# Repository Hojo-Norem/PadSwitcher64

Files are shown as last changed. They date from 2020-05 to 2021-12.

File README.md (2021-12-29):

# PadSwitcher64
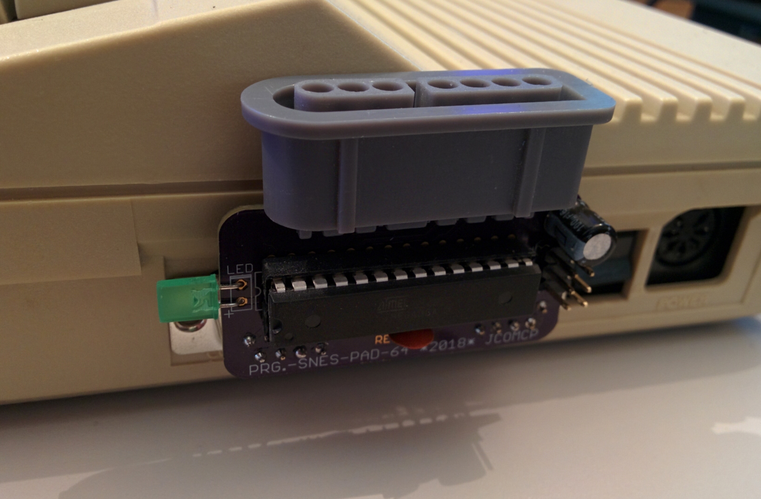
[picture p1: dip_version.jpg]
PadSwitcher64: DIP version

Interface to allow Super Nintendo (SNES) control pads to be plugged into a C64's joystick ports.

The adapter connects to both C64 joystick ports and allows the active port to be changed on the fly with a push of a button.  The interface defaults to joystick port two on power on.

Also, the interface allows up to four custom mappings to be programmed using a C64-side application.  The custom mappings allow any combination of joystick port two and port one control lines to be mapped to any of the Super Nintendo controller action buttons (A,B,X,Y,L,R).  Any of the action buttons can also have an optional rapid-fire function applied, of which a normal and 'inverted' state is available.  'Inverted' rapid fire is simply that when active the output state of the effected button will be opposite to of a normal rapid fire button when pushed.  For example, mapping a button to joystick left with rapid fire and another button to joystick right with inverted rapid fire will simulate a rapid left/right joystick waggle when both buttons are pushed.

This code was originally developed for the Atmel ATMega8 mcu and was then later ported over to the ATMega88.  This was mainly due to the availability of the Mega8 and that the Mega88 has more power saving features.

This source code was written using AVR-GCC and AVR Libc.  The C64-side software was written in Notepad++, tokenised to CBM BASIC using C64List and then compiled using "BASIC 64".  The machine code portion was assembled using 64tass.

**A pre-compiled HEX file for the AVR and the C64-side software for setting the custom mappings can be found in the releases section.  Once sucessfully programmed, the LED indicator will flash for a couple of seconds on every subsiquent power-on.**

**Mega88 fuse settings: CKDIV8 disabled, all other fuses at factory defaults.**

**PCB has been uploaded to OSH Park ( https://oshpark.com/shared_projects/Fk2LAkUS ) where they can be ordered in multiples of three.**
	
# TODO :
  * Re-jig command mode for potential compatibility with non-C64 Atari joystick compatible machines.
  * Maybe figure out how to support two pads while still retaining some semblance of mapping support.
	
# Pad Mapping: (default)
|SNES|C64|
|---|---|
|DPAD UP|UP|
|DPAD DOWN|DOWN|
|DPAD LEFT|LEFT|
|DPAD RIGHT|RIGHT|
|Y|FIRE|
|X|TURBO FIRE|
|B|UP|
|A|'Special'(*1)|
|R|KEYBOARD MATRIX LINE(PORT 2 MODE ONLY)(*2)|

(*1) -  UP + FIRE or DOWN + FIRE, swapped with SELECT + L.

(*2) - Defaults to PB4 which most software will interpret as the SPACEBAR.

# Fixed Controls:
|Button/Combo|Function|
|---|---|
|SELECT + UP|Toggle disable of D-PAD UP|
|START|Swap Joystick control port|
|SELECT + L|Toggle 'Special' function|
|SELECT + R|Change keyboard matrix line (*3)|
|SELECT + DOWN|Toggle TURBO FIRE rate|
|SELECT + (A,B,X,Y)|Select mapping| 
|SELECT + START|Default Mapping|	
|SELECT + START|Enter Command Mode (*4)| 
|SELECT + START + L + R| |
|(In normal or mapped mode)|Enter type 1 direct mode|
|(In any other mode)|Force normal mode|

(*3) - Joystick port 1, which corresponds to CIA 1 PB0 to PB4, PB4 which are normally used as the keyboard input lines during keyboard scanning.  By default at startup this is set to PB4, which most software will interpret as the SPACEBAR.
|CIA1 PortB|CIA1 PA7|PA6|PA5|PA4|PA3|PA2|PA1|PA0|
|---|---|---|---|---|---|---|---|---|
|**PB4**|SPACE|R-SHIFT|.|M|B|C|Z|F1/F2|
|**PB3**|2|CLR/HOME|-|0|8|6|4|F7/F8|
|**PB2**|CTRL|;|L|J|G|D|A|CRSR|->/<-|
|**PB1**|<-|*|P|I|Y|R|W|RETURN|
|**PB0**|1|£|+|9|7|5|3|INST/DEL|

(*4) - Only functional when prompted, only functional in default mapping mode.

# MAPPING
Four mappings, each with all 6 action buttons available.  Each button has a 2 byte pattern corresponding to the following:
|Byte/Bit|Function|
|---|---|
|Byte 1 - Bit 0 to 3|PB0 to PB3 (JOY 1 Directions & KB matrix)|
|Byte 1 - Bit 4 to 7|PA0 to PA3 (Joy 2 directions)|
|Byte 2 - Bit 0|PB4 (Joy 1 Fire & KB matrix)|
|Byte 2 - bit 1|PA4 (Joy 2 Fire)|
|Byte 2 - bit 2|Pad Button has turbofire action|
|Byte 2 - Bit 3|Pad Button has turbofire action (inverted)|
		
Bits 4 - 7 of byte 2 are not accessible through the command interface at this time.
			
# Direct mode - Type 1
Direct mode allows all the SNES control pad buttons to be read by the C64.  Type 1 uses both joystick port to report all buttons.  There is technically a direct mode type 2, and that is by using the command interface.  Type one is much faster as it just involves reading the joystick ports normally. 
|SNES Pad|C64 CIA|Bit pattern|C64 Joystick|
|---|---|---|---|
|Up|DC00| 11110|Port 2 up|
|Down|DC00|11101|Port 2 down|
|Left|DC00|11011|Port 2 left|
|Right|DC00|10111|Port 2 right|
|Y|DC00|01111|Port 2 fire|
|Start|DC00|00000|Port 2 all|
|B|DC01|11110|Port 1 up|
|X|DC01|11101|Port 1 down|
|L|DC01|11011|Port 1 left|
|R|DC01|10111|Port 1 right|
|A|DC01|01111|Port 1 fire|
|Select|DC01|00000|Port 1 all|

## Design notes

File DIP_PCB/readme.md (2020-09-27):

# BOM

1 x Atmel/Microchip AVR ATMega88 in 28 pin DIP package.  Any speed grade will do.

(Optional) 1 x 28 pin DIP socket.  If you ommit this part the the resistor will need to be soldered
  to the reverse side of the PCB, taking care to leave as little amount of leg protruding underneath
  as possible.

1 x 330 Ohm resistor

1 x LED (any regualr LED will do)

1 x 100nF ceramic capacitor

1 x 100uF electrolytic capacitor

1 x 3-by-2 pin header.  Optional if you are going to program the AVR out of circuit.

1 x SNES control port socket.  Straight pin or right angled by your preference.  The PCB is able to accomodate
  the sockets that use the thicker pins.

2 x Female DB9 plug/socket with straight PCB mounts.  When soldering I recommend spacing them out from the PCB
  a couple of mm.

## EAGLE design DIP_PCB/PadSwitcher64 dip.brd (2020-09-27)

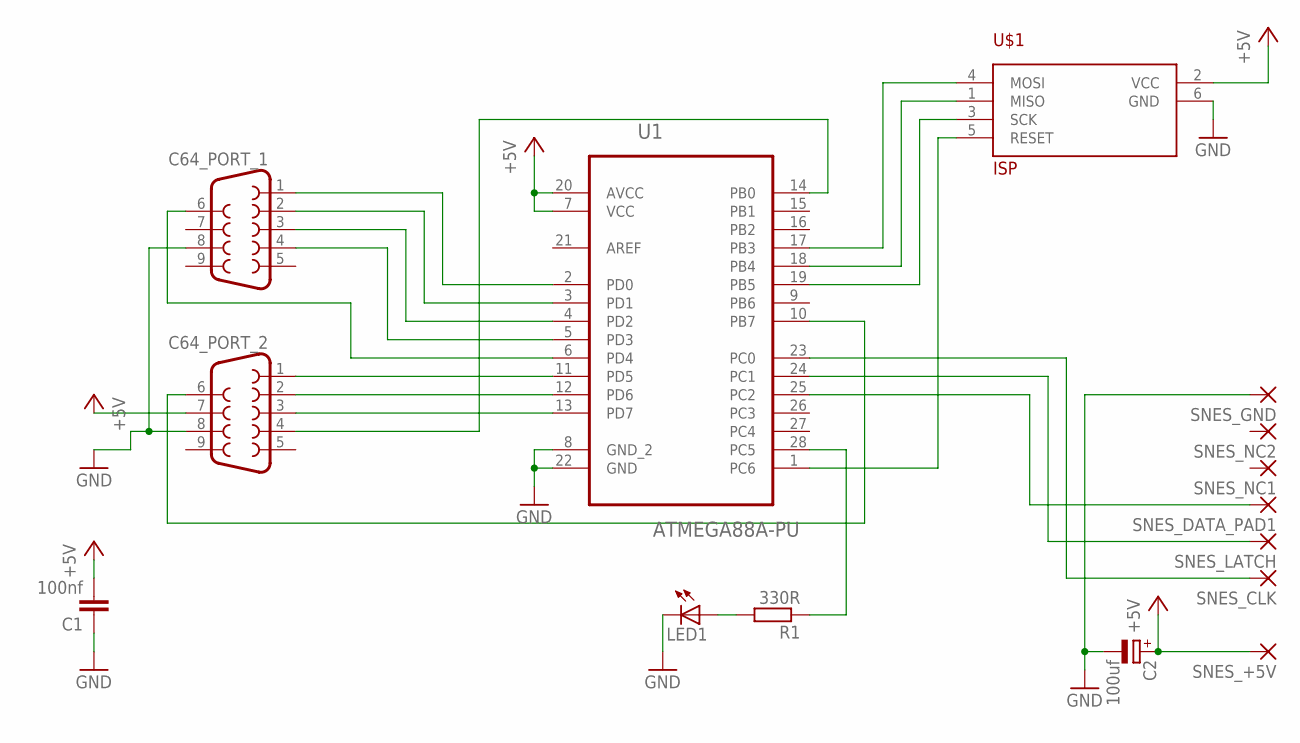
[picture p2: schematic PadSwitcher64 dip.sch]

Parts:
C1: 100nf; C050-024X044
C2: 100uf; E2,5-5
C64_PORT_1, C64_PORT_2: F09; F09VB_NO_SHELL
LED1: LEDSQR2X5; LED2X5
R1: 330R; 0207/10
SNES_+5V: 3,17/1,1
SNES_CLK: 3,17/1,1
SNES_DATA_PAD1: 3,17/1,1
SNES_GND: 3,17/1,1
SNES_LATCH: 3,17/1,1
SNES_NC1, SNES_NC2: 3,17/1,1
U1: ATMEGA88A-PU; DIL28-3
U$1: ISP; MA03-2

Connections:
+5V: C1.2, C2.+, C64_PORT_2.7, SNES_+5V.1, U1.7 (VCC), U1.20 (AVCC), U$1.2 (VCC)
GND: C1.1, C2.-, C64_PORT_1.8, C64_PORT_2.8, LED1.K (C), SNES_GND.1, U1.8 (GND_2), U1.22 (GND), U$1.6 (GND)
unnamed: U1.1 (PC6), U$1.5 (RESET)
unnamed: U1.19 (PB5), U$1.3 (SCK)
unnamed: U1.18 (PB4), U$1.1 (MISO)
unnamed: U1.17 (PB3), U$1.4 (MOSI)
unnamed: C64_PORT_1.1, U1.2 (PD0)
unnamed: C64_PORT_1.2, U1.3 (PD1)
unnamed: C64_PORT_1.3, U1.4 (PD2)
unnamed: C64_PORT_1.4, U1.5 (PD3)
unnamed: C64_PORT_1.6, U1.6 (PD4)
unnamed: C64_PORT_2.6, U1.10 (PB7)
unnamed: C64_PORT_2.1, U1.11 (PD5)
unnamed: C64_PORT_2.2, U1.12 (PD6)
unnamed: C64_PORT_2.3, U1.13 (PD7)
unnamed: C64_PORT_2.4, U1.14 (PB0)
unnamed: SNES_CLK.1, U1.23 (PC0)
unnamed: SNES_LATCH.1, U1.24 (PC1)
unnamed: SNES_DATA_PAD1.1, U1.25 (PC2)
unnamed: R1.1, U1.28 (PC5)
unnamed: LED1.A, R1.2

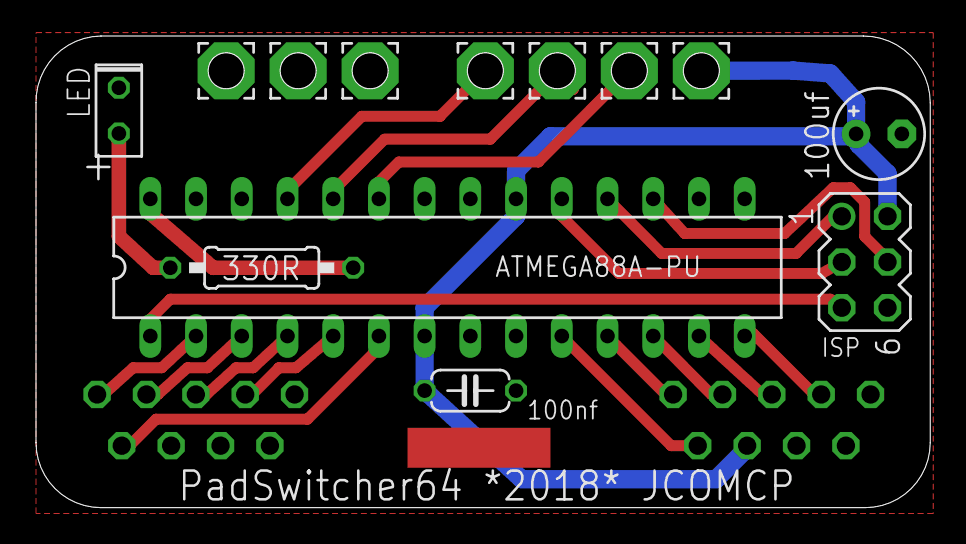
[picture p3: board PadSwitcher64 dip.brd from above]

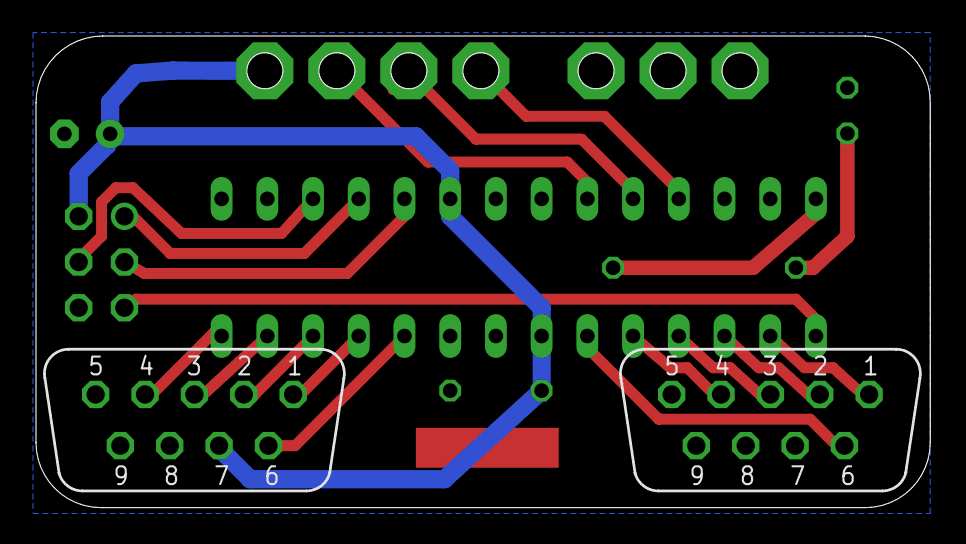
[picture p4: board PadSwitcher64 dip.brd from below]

Board: 2 copper layers, 49.7 x 26.2 mm, 15 parts (2 on the bottom side), 21 nets.

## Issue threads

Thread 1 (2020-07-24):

PadSwitcher64 C64 software doesn't appear to work on NTSC machines

misterblack1, 2020-07-24:
Running the PRG, it asks to hit start and select on the control pad. When I do this, there is a slight flash on the screen and then a few seconds later it says "Communication Timeout with the interface!"

PadSiwtcher64 does work fine otherwise -- and pressing the button on joystick 2 enters a regular test screen and all the functions are working properly.

Is there anything I can do to troubleshoot?

Adrian (from Adrian's Digital Basement)

Hojo-Norem, 2020-07-24:
Hi.  The screen flash is a little debugging indicator.  The fact that it just
flashes and does not stick tells me that it is working to a degree.  It just
looks like that the effect that the difference in CPU clock speed between PAL
and NTSC is greater than I thought and the negotiation just times out sooner
on NTSC.

I've tripled the timeout length and attached the updated executable.  If it
works for you I'll update the GitHub.

[PadSwitcher64.zip](https://github.com/Hojo-Norem/PadSwitcher64/files/4970655/PadSwitcher64.zip)

misterblack1, 2020-07-30:
Ok sorry for the delay in testing. Just gave it a try and sadly no luck!

https://www.youtube.com/watch?v=v7ZLdolSgAk&feature=youtu.be

Different but still a timeout. Incidentally I tested this machine using Sven's diagnostic test harness and it shows up as fully working (in case there might be a 6526 issue)

Hojo-Norem, 2020-07-30:
Okay.  There should be no trouble with your hardware, it's just my underestimation of the differences between PAL and NTSC.  If there was HW issue then there's a good chance that the interfere would refuse to even begin handshaking and you would see no reaction at all on screen.

With the first version, did the border remain black or coloured after the flash?  A brief flash to black means there's a timeout during 'normal' communication while a solid white or red border means timeout during handshaking.

Try this build.  I had forgotten that there are three separate timeout checks in my code and I had gone and altered the wrong one!

[PadSwitcher64.zip](https://github.com/Hojo-Norem/PadSwitcher64/files/4999527/PadSwitcher64.zip)

misterblack1, 2020-07-30:
It was red -- check out the youtube video I posted there you can see it in action. :-)

Ok I'll try the next build and see.

Hojo-Norem, 2020-07-30:
Thanks.  If it still does not work, keep an eye on the LED on the interface.  Depending on where the timeout is occurring, the LED will flash for roughly two seconds or roughly five seconds.

misterblack1, 2020-08-01:
https://youtu.be/e2LAi0TGnCE

Hi unfortunately it's still not working. I used your updated 30th of July version and no visible change. See video. I also recorded what the LED is doing -- it's the two second flash.

Hojo-Norem, 2020-08-01:
I think I'm getting down to the source of the problem, but at the moment I'm not much closer on a solution.

Compare what you see with what supposed to happen: https://youtu.be/BsXZNpseAn4

What is a flicker of a few dozen raster lines on my PAL machine is tens of frames on your NTSC model.  The short blink sequence on the interface tells me that the handshake is timing out on the interface side first.  I wonder if the 60Hz refresh and associated interrupts are fouling things up...

I'm going to re-write the communications section in assembly.  At least that way I can disable interrupts during communications and I can't be sure of how the compiled BASIC is behaving in NTSC land.

Hojo-Norem, 2020-08-02:
Okay, re-write done.  It seems that the main issue stemmed from the C64 acting too quickly because even my poor attempt at 6502 machine code is faster than the compiled BASIC.  Fast enough that it broke until I put delays into the code.

Give this one a try.  If it does not work and the time-out border is CYAN, hit RUN/STOP+RESTORE as prompted then enter:
`POKE 50000,20`
`POKE 50001,64`
`POKE 50002,128`
`POKE 50003,5`
before typing RUN.  If it STILL does not work, re-type the last POKE, increase the 5 to 6 and re-RUN.

[PadSwitcher64.zip](https://github.com/Hojo-Norem/PadSwitcher64/files/5012663/PadSwitcher64.zip)

Hojo-Norem, 2020-09-09:
Hi.  Any chance to try this version yet?

misterblack1, 2020-09-22:
Hi!! Sorry I have just been so busy. Let me test it out right now. I'm intending to put out the video with your PadSwitcher64 this weekend, so it would be great to get this working for NTSC machines. :-)

misterblack1, 2020-09-22:
Ok --- tried out your rewrite- There are 3 PRG files in the zip, so I tried all 3 and none work. Which one had the re-write you mention? So all of them give the red border -- haven't ever seen CYAN border with the timeouts.

I tried the pokes on all 3 PRG files anyway up to 50003,7 with no luck.

You know, just for fun let me try another C64 -- I think I've done all my testing on my ZIF64.. who knows maybe it has a fault or some kind?

misterblack1, 2020-09-22:
Ok wow, I'm so sorry-- I just tried all 3 PRG files on another NTSC C64 (a shortboard this time.) The first two PRG files totally worked perfectly! The first one was pretty sluggish but the second ones worked fine too and wasn't slow. The third one worked on the first try -- but all subsequent tried give me communication error 159. The others work still -- I did get a CYAN border one time on the 2nd PRG but it worked every other time I tried it.

I also tried it with and without JaffyDos (a JiffyDos variant) and it seemed to make no difference.

 Let me break out a couple more machines to test on -- but how are you communicating with the MCU in the pad switcher? What might be causing it not work on my ZIF-64?

misterblack1, 2020-09-22:
OK yes tried on a 3rd machine -- another breadbin same revision as my ZIF64 and it works fine too. So clearly something is faulty on my ZIF64 machine that's causing a problem.

To summarize: PadSwitcher64.prg works reliably on NTSC machines. PadSwitcher64-basic.prg works too but is slow. PadSwitcher64unopt.prg does not work -- gives error 159 on both machines I tried. (It did work just one time.)

Sorry for making you chase all these issues when my C64 may have been the issue all along!!

Hojo-Norem, 2020-09-22:
The C64 > MCU communications relies on the fact that the control port lines are just essentially programmable IO lines connected to one of the CIAs.  All I do is set some of them to output and use them to talk to the MCU.  Some C64 board revisions have direct connections from the CIA to the control ports while others have various filtering components on the lines, like my short board C64 that I developed the PadSwitcher on.

The PadSwitcher64.prg software is essentially compiled BASIC with a little handwritten assembly.  PadSwitcher64-basic is the exact same but uncompiled and therefore slow while PadSwitcher64-unopt is compiled but without any of the compilers optimisations turned on.

misterblack1, 2020-09-22:
Ah cool! Makes sense. I must have faulty 6526 chip(s) on my ZIF64 machine. Luckily both chips are socketed so I should be able to figure out what is bad.

So I'd say time to update your readme if you haven't already to say it works with NTSC machines too! Thank you for the great project!

Kalidomra, 2022-01-14:
Using an NTSC 64C, I was only able to get it to work using the last posted prg with the POKE statements and using POKE 50003,8. However initially when pressing the start and select, I need to hold it down for a few seconds.

Closed 2020-09-22.

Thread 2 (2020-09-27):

Where can you buy one of these?

shifters67, 2020-09-27:
Sorry,

not really an issue - where can you buy one of these - seen it on Adrians Channel and looks interesting!

cheers

Shifters

Hojo-Norem, 2020-09-27:
I'm afraid that I don't think that there is anybody selling these.  That being said, as this project is open source, anybody is free to do so.  If you know how to solder then assembling one isn't difficult.  The PCB can be ordered from OSH Park.

jjmarcos, 2021-02-25:
Great project!

Another one interested on buying one that comes pre-assembled.
Please let us know if you plan to build a few of them and put them up for sale somewhere.

Thanks!

Hojo-Norem, 2021-02-25:
A quick Google search has turned up two places selling operational units.

https://www.ebay.co.uk/itm/PadSwitcher64-SNES-controller-to-Commodore-C64-joystick-adapter-EU-seller-/293861883455
Is selling them with a 3D printed shell, while
https://cbmretro.fi/product/padswitcher64-snes-sfc-controller-adapter-for-c64/
is selling them without a shell.

jjmarcos, 2021-02-26:
I tried to look for it, but apparently I wasn't so lucky.

Thanks for the quick response and again for making this awesome project an Open Source one.

andrasbiro, 2021-03-28:
Would you mind putting this PCBWay too? For some reason OSHPark packages tends to lose when I order them to my home address, so I prefer pcbway. Not hugely important, I can probably generate the gerbers and upload myself, but pcbway gives 10% to the author - though that's just 0.5$ for most orders.

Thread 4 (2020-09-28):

8bitdo Wireless Controller

Icelvlan88, 2020-09-28:
Hello,

Would this work with an 8bitdo wireless controller?

Thanks!

Hojo-Norem, 2020-09-28:
If it's designed to work with an actual SNES then I don't see why not.

Icelvlan88, 2020-09-29:
Which programmer do you recommend?

Hojo-Norem, 2020-09-29:
If you are only buying a programmer for this project then a cheap USBASP from ebay will do the job.  Just make sure you get one with a 6 pin cable or adapter.  There seems to be two styles of adapter on ebay, one with a narrow 6 pin connector and one with a slightly wider one.  Go for the narrow one.  USBASP drivers can be obtained from the official page: https://www.fischl.de/usbasp/

Software is a bit of a minefield, so my recommendation for Windows users is AVRDUDESS.

Icelvlan88, 2020-09-30:
Thanks, is the PCB complete? I see there was just a new revision.

Hojo-Norem, 2020-09-30:
The new revision is to allow the straight pin SNES sockets to fit properly and fix up some of the component values on the silkscreen.
I don't plan on doing any more than that.

Icelvlan88, 2020-10-12:
Can this be set up for 2 player?

tyristori, 2021-05-26:
I have 8bitdo's wireless SF30 controller with SNES wireless adapter dongle and it works great with PadSwitcher64.

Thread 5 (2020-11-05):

Wierd problem when trying to build one

rainisto, 2020-11-05:
Does the picture on front page match the current design (as 100uF seems to be wrong way there)?

What might be wrong that when I switch power on when this device is attacted, then keyboard stops working. (And there is no light on led). Just wondering what would be most common error when building this? I flashed the atmega88 with tl866 with CKDIV8  unticked.

rainisto, 2020-11-05:
When I downgraded to 1.11 hex then device starts to blink during start. so looks like that 1.1111 hex did have some changes which caused problems on my PAL machine.

Hojo-Norem, 2020-11-06:
There is a slight layout change between the PCB in the picture and the one in the source.  The orientation of the cap is one of the changes.

It turns out that I uploaded the v1.1111 hex by mistake.  That hex was meant for Adrian Black's (of Adrian's Digital Basement) SMD version of PadSwitcher.  v1.11 is the current version.

The LED blinking on power in is normal.

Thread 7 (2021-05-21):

Programming

Icelvlan88, 2021-05-21:
Should I be able to program the atmega88 soldered right on the board with the ISP pins? I've tried multiple times with 2 different  programmers and have no luck.

I keep getting "chip enable program error" and "stk500_getsync()..."

Maybe I have a dead chip.

Hojo-Norem, 2021-05-21:
That's what the ISP pins are for.  I've had no problems with my cheap USBAsp clone with AVRDUDE.  Your programmer should be supplying +5v and don't program while plugged into your C64.  Depending on your programmer you may need to reduce the programming speed.  The USBAsp and AVRDUDE at default speed is too fast for a fresh mega88.  With my USBAsp I either need to enable its slow mode jumper or add the command '-B 8' to AVRDUDE's command line.

If one of your programmers has a socket that you can slot your mega88 directly then try that.  That should prove if it's faulty or not.

Icelvlan88, 2021-05-22:
I just tried that and still no luck. I just ordered a new atmega88pu to try another.

Icelvlan88, 2021-05-22:
Do you have a 3D printable case? I saw some pictures online of some

Icelvlan88, 2021-05-22:
Do you have a 3D printable case? I saw some pictures online of some.

Hojo-Norem, 2021-05-22:
I guess that it's possible to have a DOA chip.  As for the case, I didn't design that.

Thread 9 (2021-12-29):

LED blinking and C64's does not work when plug in the PadSwitcher

unebonnevie, 2021-12-29:
Hi,

I just assembled one.  Flashed the firmware to the ATMEGA88A successfully.  Checked everything thrice.  Plug in the adapter.  The LED blinks for a couple seconds.  My C64's does not work when the adapter is plugged in.  Unplug it and my C64's keyboard works fine.  Strange!

Thanks for any tips.

Hojo-Norem, 2021-12-29:
The flashing on power on is normal.  It's to indicate that the firmware is operating. If your C64 is powering on to the normal blue screen but the keyboard is unresponsive until you unplug the adapter, then that sounds like what happens if you plug a normal joystick into port 1 and hold up.

My initial suggestion would be to pull the AVR from it's socket and plug the adapter back into your C64.  If the keyboard still misbehaves then you have a short circuit on the adapter.  With the AVR still unplugged, check for continuity on the adapter's joystick port pins between each other and the SNES port pin closest to the LED.

If that checks out okay then it looks like you may have a faulty AVR.

If neither of these were of assistance then a few good photos of your build may help root out the cause.

unebonnevie, 2021-12-30:
Thanks for the response.  My AVR ATMEGA88A is a good chip.  I got it from Digikey.com and it's programmed successfully, thus seeing the blinking LED.  I had also make sure that the fuse bits have the DIV8 bit OFF, meaning that it runs at 8Mhz internally.

My C64's keyboard does not respond with the ATMEGA88A in or not.

I checked and checked every solder point.  Everything looks fine.  I guess I'll build another.

Attached are some photos.

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

Hojo-Norem, 2021-12-30:
Odd.  Soldering looks good...  My only guess is that there was a defect in the PCB when it was made.

I see that you've mounted your SNES socket so it faces away rather than up.  Nothing wrong with that.  The reason that the holes for the socket are so much larger is so you can use the SNES sockets with the shorter, thicker, straight legs...  Which no longer seems to be available from what I can see.

These grey sockets with the bent legs seem the the most common now.

The reason I bring this up is that I soldered the socket on my first prototype similar to how you have, only for it to tear the pads away from the PCB.  It may be worth bending the pins straight before your second attempt.  The two inner pins of the group of three aren't used, so they are good candidates to see if the pins will bend without snapping.

unebonnevie, 2021-12-30:
Thanks for the response.

>My only guess is that there was a defect in the PCB when it was made

I hope not, because I got the gerber files from your github :-) I'll make another one, since I have 4 PCBs left.  We'll let you know how that goes.  Unfortunately, that SNES connector was my last one, pending on an order for more connectors.  Maybe I can desolder it off the current board.

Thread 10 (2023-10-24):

Fire button 2

magmadragoon, 2023-10-24:
Can it be added? MegaSwitcher64 has the option.

Hojo-Norem, 2023-10-26:
Short answer - Yes, but needs work.

Long answer - Yes.
Bodging in the needed resistors into a already built unit is easy for anybody half competent with a soldering iron.
Next the firmware needs to be altered so it actually works, not difficult for somebody familiar with AVR LibC.
To complete the package the C64 configuration software needs to be updated to allow the new buttons to be user mapped.

magmadragoon, 2023-10-27:
But there are no planned 'official' firmware updates?
I could do the soldering part but unfortunately the programming is out of my pay grade.
Oh, well, I'm happy with my unit and it's only a few games that use Fire 2, recently released SNK vs Capcom made prompted me to ask, I'll live ;)

Hojo-Norem, 2023-10-27:
Actually...  not too long ago I decided to have a go at implementing the protocol for the upcoming ProtoPad.  Took that as an excuse to redesign the PCB, add FIRE2 and FIRE3 capability and re-write the firmware (make the configuration protocol more NTSC friendly).  Heres the current prototype:
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
I've been working on it on and off and once it's done I should be able to back port it to the original PadSwitcher64 PCB, with the understanding that some soldering will be needed to make it work.

There's no ETA at the moment as there's many other things vying for my recreation time currently, but seeing interest helps. ^_^

magmadragoon, 2023-10-28:
Alright, looking forward to it, whenever it comes out.
Thank you for creating this.

magmadragoon, 2024-04-06:
Just a friendly reminder that I'd love to see this done one day :)

Hojo-Norem, 2024-04-08:
Funny you should say that...  I was just plugging away at it some last week.  Working on the Protopad compatibility mode has been driving me mad.  I've managed to get it working 100% as far as I can tell with the tester application that was bundled with the first revision of the Protopad dev guide and with the Protopad mode in the 'Joyride' joystick tester.

Now, with the two games I could find and download that have Protopad features, 'Muddy Racers' works fine at the title screen and menus, but then proceeds to act as if a Protopad isn't plugged in when actually playing, only to start working again when paused and then stop working when unpaused...

The other game, 'Deathflood', fares much better somewhat but is far from perfect.

I'm spending as much time as I am on this because... well just how many different multi-button pad interfaces, each having their own protocol, are there for the C64?  How many are supported by more than one or two games?  The scene needs to stop re-designing the wheel and I think by supporting the Protopad protocol, which has at least two commercial games supporting it even though the actual Protopad hasn't been released yet, then there may be more impetus for games makers to add support.

Anyhoow, here's a WIP image of the next and probably final revision of the PadSwitcher64Plus PCB.
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
When I finally do release, I'll most likely create a new repository for it.

magmadragoon, 2024-04-11:
Gotta admit this is the first time I've heard ot the Protopad, I see it has a ton of buttons. Most other new C64 sticks/pads or adapters only have 2, and I doubt any game needs more than that. There is a person working on adding 2nd button support for a bunch of old games by changing one game at a time.

I'm very happy to see progress here. Will I be able to modify the original padswitcher board to support this?

rainisto, 2025-08-17:
Any updates on this one? :)

magmadragoon, 2025-08-24:
I am definitely interested in getting fire 2 working if possible, but I'm a complete noob when it comes to these things so I will need detailed instructions if I need to change code or solder something.

rainisto, 2025-08-24:
Published soldering and flashing instructions, changes and modified .hex in my forked repo: [https://github.com/rainisto/PadSwitcher64](https://github.com/rainisto/PadSwitcher64). Let me known if instructions are clear enough of not.

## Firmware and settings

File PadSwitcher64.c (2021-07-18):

#include <avr/io.h>
#include <util/delay.h>
#include <avr/eeprom.h>
#include <avr/interrupt.h>
#include <avr/sleep.h>
#include <avr/power.h>

/*
    This file is part of PadSwitcher64.

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

	************************************

				PADSwitcher64
				
	************************************
	
	V1.1 - Added turbo fire speed toggle
	v1.11 - Fixed being unable to enter direct mode.
	
	Hardware and software design my Hojo Norem.
	
	*2018*

	Super Nintendo control pad interface for the Commodore 64 (and probably the C128).
	
	The adapter connects to both C64 joystick ports and allows the active port to be
	changed on the fly with a push of a button.
	
	Also, the interface allows up to four custom mappings to be programmed using a C64-
	side application.  The custom mappings allow any combination of joystick port two
	and port one control lines to be mapped to any of the Super Nintendo controller
	action buttons (A,B,X,Y,L,R).  Any of the action buttons can also have an optional
	rapid-fire function applied, of which a normal and 'inverted' state is avaliable.
	
	'Inverted' rapid fire is simply that when active the output state of the effected
	button will be opposite to of a normal rapid fire button when pushed.
	For example, mapping a button to joystick left with rapid fire and another button
	to joystick right with inverted rapid fire will simulate a rapid left/right
	joystick waggle when both buttons are pushed.
	
	This code was originally developed for the Atmel AVRMega8 mcu and was then later
	ported over to the AVRMega88.  This was mainly due to the availiablilty of the Mega8
	and that the Mega88 has more power saving features.
	
	This source code was written using AVR-GCC and AVR Libc.
	
	
	TODO :
		* Re-jig command mode for potential compatibility with non-C64 Atari joystick
		  compatible machines.

	
	Pad Mappinng: (default)
	
	SNES				C64
	-----------------------
	DPAD UP				UP
	DPAD DOWN			DOWN
	DPAD LEFT			LEFT
	DPAD RIGHT			RIGHT
	Y					FIRE
	X					TURBO FIRE
	B					UP
	A					'Special' - UP + FIRE or DOWN + FIRE	
	R					KEYBOARD MATRIX LINE(PORT 2 MODE ONLY), defaults to PB4 which
						most software will interpret as the SPACEBAR.

	Fixed Controls:
	---------------
						
	SELECT + UP					TOGGLE DISABLE DPAD UP
	START 						SWAP CONTROL PORTS 
	SELECT + A					CHANGE SPECIAL (default mapping only)
	SELECT + DOWN				Change TURBO FIRE speed between FAST and SLOW.  Power on default is FAST.
	SELECT + L					Swap 'Special' function between 'DOWN + FIRE' and 'UP + FIRE'.
	SELECT + R					SELECT KEYBOARD MATRIX LINE (CIA 1 PB0 to PB4, PB4 default at startup, PORT 2 MODE ONLY, default mapping only)
									PB4 = SPACE		R-SHIFT		.		M		B		C		Z		F1/F2
									PB3 = 2			CLR/HOME	-		0		8		6		4		F7/F8
									PB2	= CTRL		;			L		J		G		D		A		CRSR ->/<-
									PB1 = <-		*			P		I		Y		R		W		RETURN
									PB0 = 1			£			+		9		7		5		3		INST/DEL


	SELECT + (A,B,X,Y)			SELECT MAPPING 
	
	SELECT + START				DEFAULT MAPPING 
	
	SELECT + START				ENTER COMMAND MODE (only functional when prompted, only functional in default mapping mode.)
	
	SELECT + START + L + R		(In normal or mapped mode) 	Enter type 1 direct mode.
								(In any other mode)			Force normal mode.
								
	
	
	MAPPING
	-------
	
	Four mappings, each with all 6 action buttons availiable.  Each button has a 2 byte pattern corrisponding to the following:
	
		Byte 1 - Bit 0 to 3		PB0 to PB3 (JOY 1 Directions & KB matrix)
		Byte 1 - Bit 4 to 7		PA0 to PA3 (Joy 2 directions)
		Byte 2 - Bit 0			PB4 (Joy 1 Fire & KB matrix)
		Byte 2 - bit 1			PA4 (Joy 2 Fire)
		Byte 2 - bit 2			Pad Button has turbofire action
		Byte 2 - Bit 3			Pad Button has turbofire action (inverted)
		
		Bits 4 - 7 of byte 2 are not accessable through the command interface.
		
		
		
		
	DIRECT MODE: TYPE 1
	-------------------
	
	SNES    Port BitDown  C64 Joy Mapping
	Up      DC00 11110    up
	Down    DC00 11101    down
	Left    DC00 11011    left
	Right   DC00 10111    right
	Y       DC00 01111    fire
	Start   DC00 00000    all
	B       DC01 11110    up
	X       DC01 11101    down
	L       DC01 11011    left
	R       DC01 10111    right
	A       DC01 01111    fire
	Select  DC01 00000    all


*/


//Board selection - 

#define DIP_PRODUCTION 0	// ATMEGA88 DIP production pcb
//#define SMD_PRODUCTION 0	// ATMEGA88 SMD production pcb



//Constants
#define INVERT_MAIN 0

#if defined DIP_PRODUCTION
	#define SNES_DAT1_DDR DDRC
	#define SNES_DAT2_DDR DDRC
	#define SNES_CLK_DDR DDRC
	#define SNES_LCH_DDR DDRC
	#define SNES_DAT1_PORT PORTC
	#define SNES_DAT1_PINS PINC
	#define SNES_DAT2_PORT PORTC
	#define SNES_DAT2_PINS PINC
	#define SNES_CLK_PORT PORTC
	#define SNES_LCH_PORT PORTC

	#define SNES_CLOCK 1
	#define SNES_LATCH 2
	#define SNES_DATA_1 4
	#define SNES_DATA_2 8
	
	
#endif
#if defined SMD_PRODUCTION

	#define SNES_DAT1_DDR DDRD
	#define SNES_DAT2_DDR DDRD
	#define SNES_CLK_DDR DDRD
	#define SNES_LCH_DDR DDRD
	#define SNES_DAT1_PORT PORTD
	#define SNES_DAT1_PINS PIND
	#define SNES_DAT2_PORT PORTD
	#define SNES_DAT2_PINS PIND
	#define SNES_CLK_PORT PORTD
	#define SNES_LCH_PORT PORTD

	#define SNES_CLOCK 16
	#define SNES_LATCH 8
	#define SNES_DATA_1 4
	#define SNES_DATA_2 2
	
	
#endif



// SNES Pad buttons
#define PAD_B 1
#define PAD_Y 2
#define PAD_SELECT 4
#define PAD_START 8
#define PAD_UP 16
#define PAD_DOWN 32
#define PAD_LEFT 64
#define PAD_RIGHT 128
#define PAD_A 256
#define PAD_X 512
#define PAD_L 1024
#define PAD_R 2048
#define PAD_CONFIG1 4096
#define PAD_CONFIG2 8192
#define PAD_L2 16384
#define PAD_R2 32768

// C64 Control port lines
#define CP_UP 1
#define CP_DOWN 2
#define CP_LEFT 4
#define CP_RIGHT 8
#define CP_FIRE 16

#define CP_DIRS 15	//All directions pressed
#define CP_ALL 31	//with fire


#define SNES_LATCH_LOW()	do { SNES_LCH_PORT &= ~(SNES_LATCH); } while(0)
#define SNES_LATCH_HIGH()	do { SNES_LCH_PORT |= SNES_LATCH; } while(0)
#define SNES_CLOCK_LOW()	do { SNES_CLK_PORT &= ~(SNES_CLOCK); } while(0)
#define SNES_CLOCK_HIGH()	do { SNES_CLK_PORT |= SNES_CLOCK; } while(0)


//#define RAPIDMAX 10 // Riapid fire rate control

//Extended registers

#define EXREGCOUNT 2




volatile uint8_t MAPPINGS[4][6][2];

volatile uint8_t EXREGS[EXREGCOUNT];

uint8_t ee_MAPPINGS[48] __attribute__((section(".eeprom")));

uint8_t ee_EXREGS[EXREGCOUNT] __attribute__((section(".eeprom")));;

uint8_t ee_EEPROM_INIT __attribute__((section(".eeprom")));

volatile uint8_t tick;

uint16_t PAD;	
uint8_t	PADPUSHED;
uint16_t RAPID;
uint8_t RAPIDSTATE;
uint8_t RAPIDMAX;
uint8_t NEWSCAN;
uint16_t COMTIMEOUT;

void ReadPads(void);

void SetupPorts(void);

uint8_t ReadCP2(void);

void SetCP2(uint8_t data);

void SetCP1(uint8_t data);

void SetLED(uint8_t data);

//void SetPOTs(Uint8_t data);

ISR(TIMER0_COMPA_vect)
{
	tick++;
}

void main(void)
{

uint8_t MATRIX;
uint8_t SWAP;
uint8_t SPECIAL;
uint8_t A;
uint8_t B;
uint8_t D;
uint8_t error;
uint8_t IMODE;
uint8_t COMMAND;
uint8_t OPERAND;
uint8_t ACKWAIT;
uint16_t NEGTIMEOUT;
uint8_t MAPPING;
uint8_t BUTTON;
uint8_t EEPROM_INIT;
uint8_t ISOPERAND;
uint8_t EXCOM;
uint8_t DISABLE_UP;
uint8_t C64_PORT[2];
uint8_t MASTERHELD;
	cli();
	CLKPR=128;						// Set 4Mhz main clock
	CLKPR=1;						//
	
	//****************************
	//Setting up system tick clock
	//****************************
	
	TCCR0A = _BV(WGM01);			// Set timer0A CTC mode
	TCCR0B = _BV(CS02) | _BV(CS00);	// Set timer0A 1024 clock divider
	OCR0A = 19;						// set timer0A compare = 19 - should be roughly 205Hz
	
	TIMSK0 = _BV(OCIE0A);				// Enable timer0A interrupt

	SetupPorts();
	
	COMMAND=0;
	
	SNES_LATCH_LOW();
	SNES_CLOCK_HIGH();
	
	SWAP=0;
	PADPUSHED=0;
	MATRIX=16;
	RAPID=0;
	RAPIDSTATE=4;
	SPECIAL = 2;

	NEGTIMEOUT =0;
	OPERAND = 0;
	ISOPERAND=0;	
	NEWSCAN=0;	
	COMTIMEOUT=0;	
	RAPIDMAX=30;
	DISABLE_UP=0;
	MASTERHELD=0;

	
	EEPROM_INIT=eeprom_read_byte(&ee_EEPROM_INIT);
	if(EEPROM_INIT==64){
		eeprom_read_block((void*)&MAPPINGS, (void*)&ee_MAPPINGS, sizeof(MAPPINGS));
		eeprom_read_block((void*)&EXREGS, (void*)&ee_EXREGS, sizeof(EXREGS));
	}else{
		for(MAPPING=0;MAPPING<=3;MAPPING++){
			for(BUTTON=0;BUTTON<=5;BUTTON++){
				MAPPINGS[MAPPING][BUTTON][0]=0;
				MAPPINGS[MAPPING][BUTTON][1]=0;
			}
		}
		//EXREGS[PADREADRATE]=13;
		//EXREGS[RAPIDMAX]=60;		//Default rapid-fire rate
	}
	
	
	MAPPING=4;
	
	BUTTON=0;
	
	ACKWAIT=0;
	


	power_adc_disable();
	power_usart0_disable();
	power_spi_disable();
	power_timer1_disable();
	power_timer2_disable(); 
	power_twi_disable();

	SetCP1(0);
	SetCP2(0);
	EXCOM=1;
	IMODE=0;
	error=10;
	tick=0;
	sei();

	for(;;){
		sleep_mode();
		if(error!=0){
			if(tick<100){
				SetLED(1);
			}else{
				SetLED(0);
			}
			if(tick==200){
				tick=0;
				error--;
			}
		}
		
		ReadPads();
		
		if(MASTERHELD<2){
			if((PAD&PAD_SELECT)==0){
				if((PAD&PAD_L)==0){
					if(((PAD&PAD_R)==0)&&((PAD&PAD_START)==0)){
						if(IMODE==0){
							IMODE=2;
							MASTERHELD=2;
							error=2;
						}else{
							IMODE=0;
							MASTERHELD=2;
							error=2;
						}
					}
				}
			}
		}
		if(MASTERHELD>=1){
			if(PADPUSHED==0) MASTERHELD=0;
		}else{
			
			//A = ReadCP2();
			if (((PAD&PAD_START)==0)&&((PAD&PAD_SELECT)==0)&&(IMODE==0)){
				if((ReadCP2()==CP_FIRE)&&(MAPPING==4)){
				/*
					Comamnd MODE
					-----------
					
					Sequence - 
					
						Interface will only enter mode if SELECT + START are pressed with bits 0-3 of port 2 from c64 low.
						Interface acks C64 by pulling all of port 1 low.
						C64 bit 4 of port 2 low and lets bit 0 go high.
						Interface acks this by inverting port 1.
						C64 acks this by pulling bit 0 of port 2 low and releasing bit 2.
						Interface aks this by inverting port 1 again.
						C64 aks this by pulling bit 2 down again.  Handshake is complete on C64 side.
						Interface waits for port 2 bit two to go low.  When it does it releases all of port 1 high.
						
						Handshake complete.

						Interface listens for commands on port 2.
						C64 issues commands by placing it on port 2.  pulls bit 4 HIGH to indicate a operand write.  Operands are written before commands.
						The operand register is 8 bits wide and is written and read in nybbles.  Before each nybble written the register is shifted left four
						bits.  After each nybble read the register is shifted right four bits.  The operand register does not wrap. 
						Interface acks commands by pulling port 1 fire (PB4) low and for read commands places register on PB3-PB0.  Reads from interface to 
						C64 are inverted.
						C64 acks reply by port 2 pulling port 2 low.
						
						
				*/
					if (IMODE==0){
						SetCP1(CP_ALL);
						SetLED(1);
						
						tick=0;
						NEGTIMEOUT=0;
						B=0;
						do{
							A=ReadCP2();
							if ((A==CP_UP)&&(B==0)){
								B=1;
								SetCP1(0);
							}
							//if ((B==1)&&((A!=CP_UP)&&(A!=CP_LEFT)))B=0;
							if ((B==1)&&(A==CP_LEFT)){
								B=2;
								SetCP1(CP_ALL);
							}
							if ((B==2)&&(A==0))B=3;
							if (tick==205){
								NEGTIMEOUT++;
								tick=0;
							}
						}while((B!=3)&&(NEGTIMEOUT<1));
						
						if(NEGTIMEOUT<1){
							OCR0A = 8;
							IMODE=1;
							SetCP1(CP_ALL);
							COMTIMEOUT=0;
							EXCOM=1;
						}else{
							SetCP1(0);
							SetLED(0);
							IMODE=0;
							error=5;
						}
					}
				
				//DDRC = 0b11111100;
				//DDRD = 0;	
				}
			}
			
			/*
				COMMANDS/REGISTERS (C64 > interface)
				------------------------------------
				
				Command page 1
				
					00 - No command / ack read
					01 - Select pad 1 (Non functional but acks)
					02 - Select pad 2 (Non functional but acks)
					03 - READ NYB 1:  B, Y, SELECT, START
					04 - READ NYB 2:  UP, DOWN, LEFT, RIGHT
					05 - READ NYB 3:  A, X, L, R
					
					06 - Write EEPROM
					   (Operand = 14)
					
					07 - Select mapping
					   (Operand = 0 to 3)
					08 - Select button
					   (Operand = 0 to 5)
					09 - Read nybble 1
					10 - Read nybble 2
					11 - Read nybble 3
					12 - Write nybble 1
					   (Operand)
					13 - Write nybble 2
					   (Operand)
					14 - write nybble 3
					   (Operand)
					
					15 - Shift to command page 2
					
				Command page 2
				
					00 - No command / ack read
					01 - Shift to command page 1
					
					********** currently not implemented, if ever *************
						02 - Select extended register
						   (Operand = register:
												
												
												
						03 - Read Extended register
						04 - Write Extended Register
						   (Operand*2 writes - Register written on 2nd write)
					***********************************************************
					
					05 - Enter Direct Mode, type 1
							NOTE: Not ACK'd.  Exits command mode.  C64 software should act accordingly
							
					06 - Enter Direct Mode, type 2
							NOTE: Not currrently implemented, may never.
					
					15 - Exit command mode
							NOTE: Not ACK'd. 
			*/
			
			
			if(IMODE==1) {
				COMTIMEOUT++;
				if(COMTIMEOUT>1025){		// ~5 second comunications timeout
					SetCP1(0);
					SetCP2(0);
					EXCOM=1;
					IMODE=0;
					OCR0A = 19;
					error=10;
				}
				COMMAND = ReadCP2()&CP_ALL;
				SetLED(COMMAND&CP_FIRE);
				if(COMMAND>=CP_FIRE) ISOPERAND=1; else ISOPERAND=0;
				COMMAND = COMMAND&CP_DIRS;
				
				
				if ((ISOPERAND==1)&&(ACKWAIT==0)){
					OPERAND = OPERAND<<4;
					OPERAND = OPERAND|COMMAND;
					SetCP1(CP_FIRE);
					SetLED(1);
					ACKWAIT=1;
				}
				
				if ((ISOPERAND==0)&&(ACKWAIT==0)){
					SetLED(0);
					switch(EXCOM){
					case 1:
						if((COMMAND==7)&&((OPERAND&15)<=4)){
							MAPPING=OPERAND&15;
							SetCP1(CP_FIRE);
							ACKWAIT=1;
						}
						
						if((COMMAND==6)&&((OPERAND&CP_DIRS)==14)){
							SetCP1(CP_FIRE);
							SetLED(1);
							cli();
							do{asm volatile ("nop");}while (!eeprom_is_ready());
							eeprom_update_block((void*)&MAPPINGS, (void*)&ee_MAPPINGS, sizeof(MAPPINGS));
							eeprom_update_block((void*)&EXREGS, (void*)&ee_EXREGS, sizeof(EXREGS));
							eeprom_update_byte(&ee_EEPROM_INIT, 64);
							sei();
							ACKWAIT=1;
						}
						
						if(COMMAND==8){
							BUTTON=(OPERAND&15);
							SetCP1(CP_FIRE);
							ACKWAIT=1;
						}
						
						if(COMMAND==9){
							SetCP1((MAPPINGS[MAPPING][BUTTON][0]&15)|CP_FIRE);
							ACKWAIT=1;
						}
						if(COMMAND==10){
							SetCP1((MAPPINGS[MAPPING][BUTTON][0]>>4)|CP_FIRE);
							ACKWAIT=1;
						}
						if(COMMAND==11){
							SetCP1((MAPPINGS[MAPPING][BUTTON][1]&15)|CP_FIRE);
							ACKWAIT=1;
						}
						if(COMMAND==12){
							MAPPINGS[MAPPING][BUTTON][0]=(MAPPINGS[MAPPING][BUTTON][0]&240)|(OPERAND&15);
							SetCP1(CP_FIRE);
							ACKWAIT=1;
						}
						if(COMMAND==13){
							MAPPINGS[MAPPING][BUTTON][0]=(MAPPINGS[MAPPING][BUTTON][0]&15)|(OPERAND<<4);
							SetCP1(CP_FIRE);
							ACKWAIT=1;
						}
						if(COMMAND==14){
							MAPPINGS[MAPPING][BUTTON][1]=(MAPPINGS[MAPPING][BUTTON][1]&240)|(OPERAND&15);
							SetCP1(CP_FIRE);
							ACKWAIT=1;
						}

				
					
					
						if(COMMAND==15){
							SetCP1(CP_FIRE);
							EXCOM=2;
							ACKWAIT=1;
						}
						
						if((COMMAND==1)||(COMMAND==2)){
							//PADSEL=COMMAND-1;
							SetCP1(CP_FIRE);
							//ReadPads();
							//AUTOREAD=0;
							ACKWAIT=1;
						}

							
						
						if((COMMAND>=3)&&(COMMAND<=5)){
							//if((AUTOREAD==1)&&(COMMAND==3)){
							//	ReadPads();
							//}
							B=0;
							D=(COMMAND-3);
							B=PAD>>(D*4);
							B=B^15;
							SetCP1(B|CP_FIRE);
							ACKWAIT=1;
							//AUTOREAD=1;
						}
						break;
					case 2:
					
						if(COMMAND==1){
							SetCP1(CP_FIRE);
							ACKWAIT=1;
						}
					
						if(COMMAND==5){
							SetCP1(0);
							SetCP2(0);
							OCR0A = 19;
							IMODE=2;
						}
							
					
						if(COMMAND==15){
							SetCP1(0);
							SetCP2(0);
							IMODE=0;
							OCR0A = 19;
							EXCOM=1;
						}
						break;
					
					}
				}
				
				if(ACKWAIT==1){
					tick=0;
					do{
						B=ReadCP2();
					}while((B!=0)&&(tick<255));
					SetCP1(0);
					if(tick==255) COMTIMEOUT=9999; else COMTIMEOUT=0;
					ACKWAIT=0;
				}
			}
			
			
			
			/*
				DIRECT MODE: TYPE 1
				-------------------
		
				SNES    Port BitDown  C64 Joy Mapping
				Up      DC00 11110    up
				Down    DC00 11101    down
				Left    DC00 11011    left
				Right   DC00 10111    right
				Y       DC00 01111    fire
				Start   DC00 00000    all
				B       DC01 11110    up
				X       DC01 11101    down
				L       DC01 11011    left
				R       DC01 10111    right
				A       DC01 01111    fire
				Select  DC01 00000    all
			*/
			
			if (IMODE==2){
				
				C64_PORT[0]=0;
				
				if((PAD&PAD_UP)==0) C64_PORT[0]|=CP_UP;
				if((PAD&PAD_DOWN)==0) C64_PORT[0]|=CP_DOWN;
				if((PAD&PAD_LEFT)==0) C64_PORT[0]|=CP_LEFT;
				if((PAD&PAD_RIGHT)==0) C64_PORT[0]|=CP_RIGHT;
				if((PAD&PAD_Y)==0) C64_PORT[0]|=CP_FIRE;
				if((PAD&PAD_START)==0) C64_PORT[0]|=CP_ALL;
				
				C64_PORT[1]=0;
				
				if((PAD&PAD_B)==0) C64_PORT[1]|=CP_UP;
				if((PAD&PAD_X)==0) C64_PORT[1]|=CP_DOWN;
				if((PAD&PAD_L)==0) C64_PORT[1]|=CP_LEFT;
				if((PAD&PAD_R)==0) C64_PORT[1]|=CP_RIGHT;
				if((PAD&PAD_A)==0) C64_PORT[1]|=CP_FIRE;
				if((PAD&PAD_SELECT)==0) C64_PORT[1]|=CP_ALL;
				
				SetCP2(C64_PORT[0]);
				SetCP1(C64_PORT[1]);
			
				
			}
			
			
			
			
			if (IMODE==0){
				C64_PORT[0]=0;
				C64_PORT[1]=0;
				
				if((PAD&PAD_SELECT)==0){
					if ((PAD&PAD_DOWN)==0){
						if(RAPIDMAX==30) RAPIDMAX=60; else RAPIDMAX=30;
						MASTERHELD=1;
					}
					if ((PAD&PAD_UP)==0){
						if (DISABLE_UP==0) DISABLE_UP=1; else DISABLE_UP=0;
						MASTERHELD=1;
					}
					if ((PAD&PAD_A)==0){MAPPING=0;MASTERHELD=1;}
					if ((PAD&PAD_B)==0){MAPPING=1;MASTERHELD=1;}
					if ((PAD&PAD_X)==0){MAPPING=2;MASTERHELD=1;}
					if ((PAD&PAD_Y)==0){MAPPING=3;MASTERHELD=1;}
					if ((PAD&PAD_START)==0){MAPPING=4;MASTERHELD=1;}		
				}
				
				if (((PAD&PAD_START)==0)&&((PAD&PAD_SELECT)!=0)){
					SWAP=SWAP^1;
					MASTERHELD=1;
				}
				B=1^SWAP;
					



				if(MAPPING==4){

					if ((PAD&PAD_SELECT)==0){
						if((PAD&PAD_START)!=0){
							if (SWAP==0){	
								if ((PAD&PAD_R)==0){
									MATRIX=MATRIX<<1;
									if (MATRIX>16) MATRIX=1;
									MASTERHELD=1;
								}	
							}
							if ((PAD&PAD_L)==0){
								SPECIAL=SPECIAL<<1;
								if(SPECIAL>2) SPECIAL=1;
								MASTERHELD=1;
							}
						}
						SetLED(1);
					}else{	
						if (((PAD&PAD_UP)==0)&&(DISABLE_UP==0)) C64_PORT[B]=C64_PORT[B]|CP_UP;
						if ((PAD&PAD_B)==0) C64_PORT[B]=C64_PORT[B]|CP_UP;
						if ((PAD&PAD_DOWN)==0) C64_PORT[B]=C64_PORT[B]|CP_DOWN;
						if ((PAD&PAD_LEFT)==0) C64_PORT[B]=C64_PORT[B]|CP_LEFT;
						if ((PAD&PAD_RIGHT)==0) C64_PORT[B]=C64_PORT[B]|CP_RIGHT;					
						if ((PAD&PAD_Y)==0) C64_PORT[B]=C64_PORT[B]|CP_FIRE;
						if ((PAD&PAD_A)==0) C64_PORT[B]=C64_PORT[B]|SPECIAL|CP_FIRE;
						if ((PAD&PAD_X)==0) C64_PORT[B]=C64_PORT[B]|((RAPIDSTATE&4)<<2);
						if (((PAD&PAD_R)==0)&&(SWAP==0)) C64_PORT[0]=C64_PORT[0]|MATRIX;
					}
					
				}else{
					if((PAD&PAD_SELECT)!=0){
						if (((PAD&PAD_UP)==0)&&(DISABLE_UP==0)) C64_PORT[B]=C64_PORT[B]|CP_UP;
						if ((PAD&PAD_DOWN)==0) C64_PORT[B]=C64_PORT[B]|CP_DOWN;
						if ((PAD&PAD_LEFT)==0) C64_PORT[B]=C64_PORT[B]|CP_LEFT;
						if ((PAD&PAD_RIGHT)==0) C64_PORT[B]=C64_PORT[B]|CP_RIGHT;
							
						if ((PAD&PAD_A)==0) {
							if((RAPIDSTATE&(MAPPINGS[MAPPING][0][1]&12))==0){
								C64_PORT[0]=C64_PORT[0]|(MAPPINGS[MAPPING][0][0]&15)|((MAPPINGS[MAPPING][0][1]&1)<<4);
								C64_PORT[1]=C64_PORT[1]|((MAPPINGS[MAPPING][0][0]&240)>>4)|((MAPPINGS[MAPPING][0][1]&2)<<3);
							}
						}
						if ((PAD&PAD_B)==0) {
							if((RAPIDSTATE&(MAPPINGS[MAPPING][1][1]&12))==0){
								C64_PORT[0]=C64_PORT[0]|(MAPPINGS[MAPPING][1][0]&15)|((MAPPINGS[MAPPING][1][1]&1)<<4);
								C64_PORT[1]=C64_PORT[1]|((MAPPINGS[MAPPING][1][0]&240)>>4)|((MAPPINGS[MAPPING][1][1]&2)<<3);
							}
						}
						if ((PAD&PAD_X)==0) {
							if((RAPIDSTATE&(MAPPINGS[MAPPING][2][1]&12))==0){
								C64_PORT[0]=C64_PORT[0]|(MAPPINGS[MAPPING][2][0]&15)|((MAPPINGS[MAPPING][2][1]&1)<<4);
								C64_PORT[1]=C64_PORT[1]|((MAPPINGS[MAPPING][2][0]&240)>>4)|((MAPPINGS[MAPPING][2][1]&2)<<3);
							}
						}
						if ((PAD&PAD_Y)==0) {
							if((RAPIDSTATE&(MAPPINGS[MAPPING][3][1]&12))==0){
								C64_PORT[0]=C64_PORT[0]|(MAPPINGS[MAPPING][3][0]&15)|((MAPPINGS[MAPPING][3][1]&1)<<4);
								C64_PORT[1]=C64_PORT[1]|((MAPPINGS[MAPPING][3][0]&240)>>4)|((MAPPINGS[MAPPING][3][1]&2)<<3);
							}
						}
						if ((PAD&PAD_L)==0) {
							if((RAPIDSTATE&(MAPPINGS[MAPPING][4][1]&12))==0){
								C64_PORT[0]=C64_PORT[0]|(MAPPINGS[MAPPING][4][0]&15)|((MAPPINGS[MAPPING][4][1]&1)<<4);
								C64_PORT[1]=C64_PORT[1]|((MAPPINGS[MAPPING][4][0]&240)>>4)|((MAPPINGS[MAPPING][4][1]&2)<<3);
							}
						}
						if ((PAD&PAD_R)==0) {
							if((RAPIDSTATE&(MAPPINGS[MAPPING][5][1]&12))==0){
								C64_PORT[0]=C64_PORT[0]|(MAPPINGS[MAPPING][5][0]&15)|((MAPPINGS[MAPPING][5][1]&1)<<4);
								C64_PORT[1]=C64_PORT[1]|((MAPPINGS[MAPPING][5][0]&240)>>4)|((MAPPINGS[MAPPING][5][1]&2)<<3);
							}
						}
					}
					// use spiffy new putput subroutines here
				}
				
				SetCP2(C64_PORT[1]);
				SetCP1(C64_PORT[0]);
				
				SetLED(SWAP);
				
				
			}
		}
	}
}

void ReadPads(void){
uint8_t i;	
	RAPID++;
	if (RAPID>RAPIDMAX){
		RAPID=0;
		RAPIDSTATE=RAPIDSTATE^12;
	}
	PAD=0;
	PADPUSHED=0;
	//PAD[16][1]=0;
	SNES_LATCH_HIGH();
	_delay_us(12);
	SNES_LATCH_LOW();
	_delay_us(6);
	for (i=0; i<=15; i++)
	{
		SNES_CLOCK_LOW();
		_delay_us(6);
		if ((SNES_DAT1_PINS&SNES_DATA_1)!=0) PAD=PAD|32768; else PADPUSHED=1;
		if (i<15)PAD=PAD>>1;
		SNES_CLOCK_HIGH();
		_delay_us(6);
	}
}

/*
	
	***** DIP and SMD prototype PCB PORT connections *****
	
	C64 control port 1 - PORTD bits 0 to 3 and PORTC bit 1
	C64 control port 2 - PORTD bits 4 to 7 and PORTC bit 0
	LED - PORTC bit 2
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

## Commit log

2020-05-06 CPU divisor and TURBO FIRE
    I wasn't setting the CPU clock divisor properly. Was running at 8Mhz instead of 4. Now Fixed. Lower speed = less power needed. Also means that the pad reading routine is running at correct speed.
    Also, added ability to switch between two TURBO FIRE speeds. Use SELECT + DOWN to toggle between FAST and NOT-SO-FAST. Some games don't respond properly to fast turbo fire rates.
    Why do I always find these things AFTER I publish?
    [PadSwitcher64.c]
2020-05-07 Fixed command interface broken with last commit
    [PadSwitcher64.c]
2020-05-09 Fixed being unable to enter direct mode
    [PadSwitcher64.c]
2020-09-27 Added extra info on AVR, SNES socket and DB9s
2020-09-27 Added extra info on AVR, DIP socket, SNES socket and DB9s
2020-09-27 Fixed component values on silkscreen.
    [PadSwitcher64 dip.brd, PadSwitcher64 dip.sch]
2020-09-27 Adjusted component positions.
    Turns out that there wasn't enough room to mount the straight pin SNES socket properly. The PCB has been enlarged a smidgen and the AVR and socket have been moved apart a little.
    [PadSwitcher64 dip.brd, PadSwitcher64 dip.sch]
2020-09-27 Adjusted component positions... again.
    Forgot to nudge the LED out to the way a little.
    [PadSwitcher64 dip.brd]
2020-09-27 Add AVR fuse settings and PCB link
2021-05-05 Fixed timer inicialization - or at least made it more portable
    [PadSwitcher64.c]

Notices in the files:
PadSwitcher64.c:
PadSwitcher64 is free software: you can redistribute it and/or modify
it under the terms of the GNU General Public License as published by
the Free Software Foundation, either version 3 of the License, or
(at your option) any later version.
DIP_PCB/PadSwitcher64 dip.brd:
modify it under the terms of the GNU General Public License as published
